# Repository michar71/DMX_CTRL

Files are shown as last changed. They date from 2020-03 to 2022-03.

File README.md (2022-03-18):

# DMX_CTRL
A DMX512-combatible light control platfrom for medium-complex projects.

There are currently standard solutions for light control that fill specific needs:
- DMX512 compatible stage lighting ($13 - $ 300) usually with Full RGB control and maybe XYZ Control
- Custom solutions for complex installations using WS1812 Strips (Fadecandy and others). This for Example: http://www.deniznicoleart.com/
- Progammable light controllers that can play back preprogrammed patterns that can get triggered by DMX512 (Chinese closed source products)

What is missing is a controller that combines the simple, low cost wiring and control of DMX512 with the flexibility of a customizable firmware and control options.

## Usage Case
The follwing is an outline of the current usage case for an art car and why a specific controller is needed. The art car has multiple light-elements that need central coordination/sequencing but also reacts to other stimulus:
- "Hoover Field" -> WS2812 Light Strips around the base that display a moving pattern syncronized with the speed of the car.
- "Engines" -> Simple RGB Strips that are playing a preprpogrammed startup/shutdown seuqence and a animation while moving
- "Internal Lights" -> Lantern with red LED's that are supposed to flicker and occasionally fail
- "Mood Lighting" -> White LED Strips that can be controlled in brightness
- "Centralized Control Panel" -> Touchscreen control to trigger and sequence effects (Either Cheap Windows Tablet or Raspberry Pi)

These are all usage cases that are not "Simple" DMX RGB-Light cases but also do not warrant complex solutions like FadeCandy that need a lot of programming, USB wiring and complex control computers.
While these effects could be achived with a handful of Arduinos it makes central control more compleicated as there is no common control bus easily available and the processing power of Arduinos is limited. 

## Feature List
-	Can act as DMX Master or Slave
-	Up to 2 WS8212 LED strips with up to 512 Pixel 
-	2x RGB LED/Strip and 1xRGBW LED/Strip support with up to 3A/12V per LED (Or optionally drive PWM controlled servos)
-	Configurable via USB/Serial Terminal
-	Up to 2 Analog Inputs (Can be used to control effects or act as Triggers)
-	8 Address Lines (Optional LCD via i2C and Encoder via GPIOs instead)
-	2 Mode Jumpers to hard-select options (Simple Mode (PWM Only) / Extended Mode (PWM+Strips+FX) and USB Enable/Disable)
-	Button to restore settings on startup or Test Mode
-	External UART or option to connect ESP8266 WiFi Board
-	USB to use as a Computer -> Master Bridge
-	Total Cost per Board ~$16 (Most of that (8$) are MOSFETs so it depends on how many LED channels are needed)
-	Board size 10x5 cm

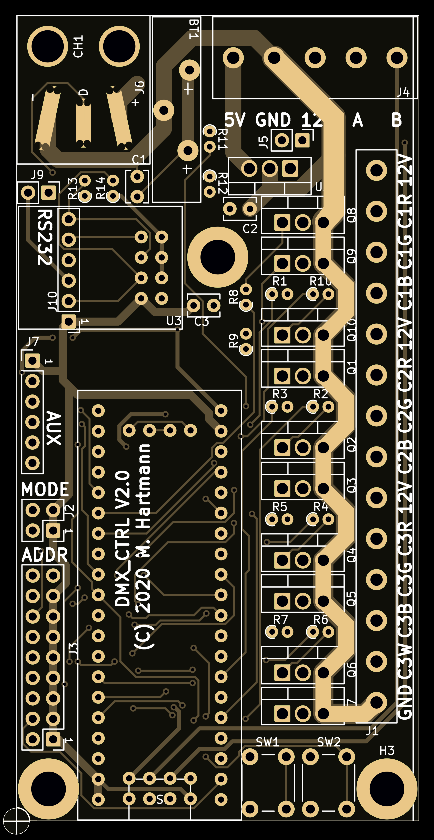
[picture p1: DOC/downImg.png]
Front PCB

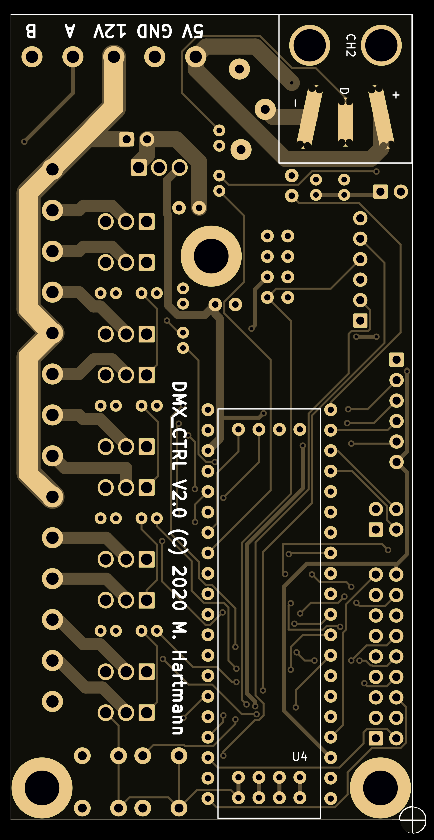
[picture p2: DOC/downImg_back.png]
Back PCB

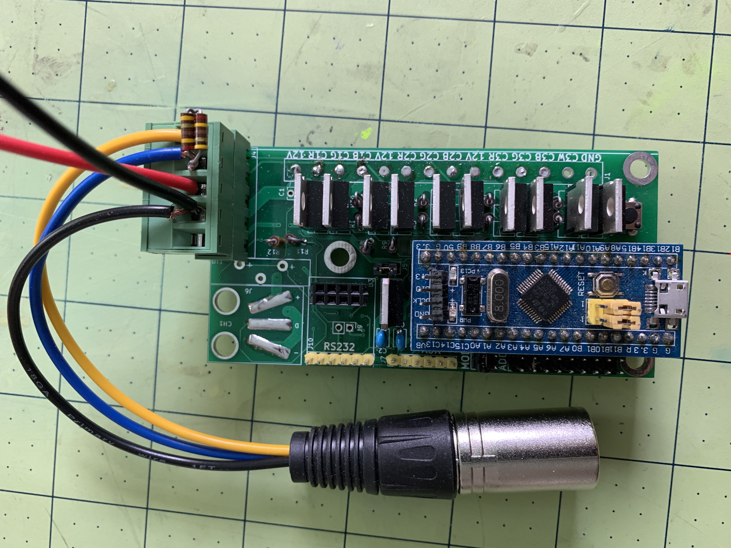
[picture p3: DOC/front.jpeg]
Front Assembled

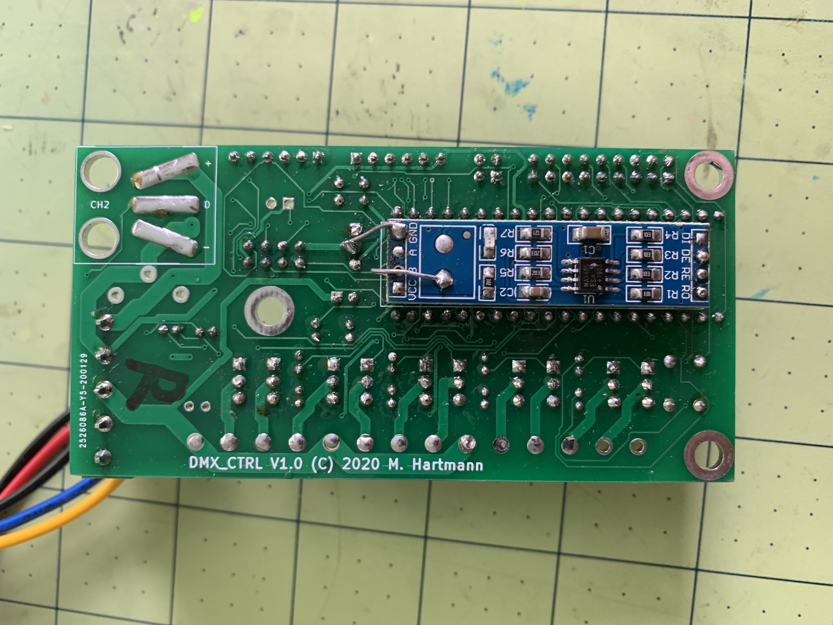
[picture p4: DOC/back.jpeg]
Back Assembled


## Current Status
- DMX512 Control of PWM Channels -> Working
- DMX Address setting via Jumpers -> Working
- Serial Shell to control/Save settings -> Working
- Load defaults on startup -> Working
- Clear settings (Hold button on power-up) -> Working
- Test Mode (Press button after power up, cycles through all LED channels) -> Working
- Triggers -> Working
- Plugin Manager -> Working
- Example Plugins -> Working
- WS2812 Support -> Working
- Serial Control (Wifi/Serial/USB) -> Working
- Serial DMX Protocol -> Working

## BOM Cost
The BOM cost for the simplest implementation is 
- $2.00 for the board
- $2.00 for the Bluepill STM32F103 Board
- $0.70 for the RS485 Module
- $4.00 for Misc (Resistors, pin headers, switch)
- $0.80 per Mosfet for controllable Channels
So somewhere between $9 to $17.

## Development Enironment
The software is developed with ST Microelectronics STM32CubeIDE 1.3.0
The software framework was generated with STM's ST CubeMX Solution (Config file included in DOC folder) and uses ST's HAL framework.
(Not my favorite but that's what they want you to use...)
I use a ST-Link V2.0 Clone to upload/Debug software. (Eventually there might be a USB DFU Firmware Upload Client....)

You can also use MS Visual Studio Code + PlatformIO. This is prefered if you run into issues with fake STM32's as PlatformIO uses openOCD which can set the device ID directly and program these devices.
There are currently a lot of bluepill STM32F103 board clones with fake STM32F103 circulating on Amazon. (I ended up with about 20...Aarrggghhh...)
As a workaround, you can edit the file ~/.platformio/packages/tool-openocd/scripts/target/stm32f1x.cfg and change the line:
set _CPUTAPID 0x1ba01477
to:
set _CPUTAPID 0x2ba01477

USB does not seem to work on my clones but I need to further test that....(I had issues like that before and usually it had to do with crappy USB cables...)

Here is another description how to fix it in STM32CubeIDE for openOCD debugging:
https://community.st.com/s/question/0D50X0000BTd7Zi/how-to-deal-wirh-could-not-verify-st-device-

Update: Not all fake chips have 128 kB, some only have 64 kB. At that point the FW can not write the configruation to page 127... This will cause a Hardware Fault. Change the EEPROM page in eeprom.h from 127 to 63 and modifiy the .id file to reflect the smaller FLASH size. (Less effects will obviously fit in there....)
I should probably figure out a way to detect flashsize automatically.....

## Serial Shell
[List of Serial Shell Commands](SHELL_COMMANDS.md)

## FX Plugin API
[FX Plugin Manual](FX_API.md)

## Notes

### DMX Registers
Depending on mode selection the module will present itself with either 11 or 26 DMX Registers.
In Mode 1 only the first 11 registers are available and provide simple PwM control.

In Mode 2 additional 15 registers are present for FX control. (WS2812B supporty will only be present in that mode...)
Except for the FX_SELECT register these don't do anything by default but have to be used in plugins. and functionality will vary.  

### Jumper Options

#### ADDRESS
The 8 Address Jumpers set the DMX Start address for the Registers.
As there are 512 possible DMX Addresses the Address set via jumpers will be multiplied by 2.

#### MODE
Jumper 1
Disabled = DMX Register Mode 1 (Only PWM Control, not FX)
Enabled  = DMX Register Mode 2 (PWM + WS2812B Strips, FX enabled

In DMX Mode 1 only the following Registers will be available:
#define MAX_BRIGHTNESS		0
#define CH1_RED				1
#define CH1_GREEN			2
#define CH1_BLUE			3
#define CH2_RED				4
#define CH2_GREEN			5
#define CH2_BLUE			6
#define CH3_RED				7
#define CH3_GREEN			8
#define CH3_BLUE			9
#define CH3_WHITE			10

In DMX Mode 2 additionally the following Registers will be available:
#define FX_SELECT		    	11
#define	STRIP1_PATTERN		12
#define STRIP1_SPEED		  13
#define STRIP1_SIZE			  14
#define STRIP1_COMPLEXITY	15
#define STRIP1_V1			    16
#define STRIP1_V2			    17
#define STRIP1_V3			    18
#define	STRIP2_PATTERN		19
#define STRIP2_SPEED		  20
#define STRIP2_SIZE			  21
#define STRIP2_COMPLEXITY	22
#define STRIP2_V1			    23
#define STRIP2_V2			    24
#define STRIP2_V3			    25

Jumper 2
Disabled = No USB Support (Saves a lot of memory)
Enabled  = Enables Serial Port via USB

### DMX Control Wires (A/B)
With my controller the follwing pinout works (Looking at a male connector):
Pin 1 = GND
Pin 2 = A
Pin 3 = B
Some controllers allow to swap A/B with a switch so your milage might vary....

### DMX Termination
DMX needs to be terminated at the end of the chain with a 160 Ohm Resistor.

### Power Supply
Board has been tested with 9 PWM channels with 216 RGB LED's with a total power consumption of 3.8A @ 12V.
If only 12V is supplied make sure to add J5 so the microcontroller is powered.

### Restoring Defaults
Pressing the button while powering up will erease all settings and restore the defaults.

### Test Mode
Pressing the button after powering up will turn on test mode where the module cycles through all lights to test wiring

### Triggers
The two trigger inputs  can be set up in different ways:

#### Direct Control
The analog value (0...3.3V) is directly mapped onto one of the control registers.
(For example an external inpout can be linked to the brightness of a channel or set the input parameter for an effect)

#### Threshold
A Specific value can be written to a specific control register wen crossing a threshold from low to high or from high to low. (For example a specific effect can be turned on/off via a switch)

### USB Port
USB Support can be complelty commented out in main.h as it saves a lot of RAM/Flash.
If USB Support is compiled in Mode Jumper 1 controls if it is eanbled or not.
USB has been confirmed working both witrh original STM32103F and STM clones but it is imperative to use good USB cables.
Also be aware that some boards will need R10 on the bluepill boards swapped from 10kOhm to 1.5kOhm. 
Both the Shell or the Serial DMX protocol can be run via USB.
On Win10 no special driver is needed, the device will be recognizied as a Serial port. The serial port emulation via USB is not speed-controlled so in theory data can be written at full 12Mbit/sec Full USB speed....

### Wifi/USB/Serial DMX Control
[TBD, Protocol Implemented, need sample App..]
[TBD, need ESP2866 Sample Code and Sample App]

### Master Control
TBD

### WS2812B
The LED strips seem to be very sensitive regarding the voltage on the data line. R11/R12 in theory protect the first LED from dying on transient overcurrent on startup but some LED strips won't work. In that case just bridge R11/R12....

### What's that strange connector footprint for the WS2812 connection?
The idea is to solder on wires and then use a zip-tie through the holes and hot-glue to secure the wires.
Past projects had big problems with wires breaking off or shortening out... Maybe this will work.....

## Acknowledgements
Example Code to use WS2812B on STM32 with DMA
https://michaeltien8901.github.io/stm32/2018/07/19/Using-STM32-SPI-For-LED-STRIP.html

DMX512 Example
https://github.com/carl3721/stm32-dmx512

## References
- DMX Pinout
https://interactive-online.com/resources/faq/dmx-512-connector-pinouts

- Fadecandy Webpage
https://github.com/scanlime/fadecandy

- Ultra-Cheap DMX Lights
(Just search for DMX512 RGB LED on ebay...)

## Part References
Bluepill Boards
https://stm32-base.org/boards/STM32F103C8T6-Blue-Pill.html

RS422 Converter
https://alexnld.com/product/2pcs-5v-max485-ttl-to-rs485-converter-module-board-for-arduino/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

(These can obviouslty be sourced way cheaper on ebay/alibaba/banggood... These links are just for reference...)

## Board Design
- Board designed with KiKad
- For various (Legacy) reasons it will need the KiCad 4.0 Symbol/Footprint Library installed...
- Board size is 100mm x 50mm. In theory these could be paneled for JCLPCB.com but there is no cost advantage if you include V-Grooves. You could just produce PCB's with two boards next to each other and cut them yourself but I haven't tried that....

## Known Issues (REV 1.0)
### Schematic:
- RX/TX Swapped on Serial Connector (TBD if they are right or wrong on ESP-01 connector...)
- GND not connected on RS485 Module
- Add Button for ESP8266 Button to trigger events on startup

### Layout:
- Make RS485 module base 2.54 mm longer (Or not.. apprently they come in two sizes.. Maybe add both sizes by adding another line of holes)
- Add silkscreen for Pin 1 to connectors
- Move RS232 Connector so it can be used in parallel with ESP-01 for Debug (Move further in so angled connector can be used....)
- Bluepill collides with mounting hole in corner
- Remove solder mask from high-current paths for tinning
- Battery collides with power connector
- Move labels for power supply to other side of connector or back
- Make holes for TO220 Larger so they fit flush
- RS485 module is rotated 180 Deg
- Create more room for programming connector on bluepill board by moving 5V Regulator
- Move Compyright Notice on Bottom to allow for Tinning
- For WS2812B Cable Connector, less extrame angle, 0.6mm smaller holes, Shink total size

## Known Issues (REV 2.0)
### Schematic:

### Layout:
- Bluepill collides with mounting hole in corner
- Panelize Board
- Mounting holes for RS485 Transceiver should have been 2.54mm smaller, not bigger?
- Holes for TO220 should have been even bigger
- No coating on 5V rail to WS2812B

## TODO
- Master Mode
- ESP-01 (ESP8266) Code/Example
- Serial DMX Protocol Example (In Processing....)
- RTC Support
- High Speed WS2812B USB Demo
- Overclocked Version

## Ideas
### WS2812B USB Mode
Run data as fast as possible via USB to 2 WS2812B strips.
(512 LED * 30 us) + 60 us = 15.4 ms (64 FPS)
512 Leds = (512 * 3) * 1.2 bytes = 1843 Bytes

1843 Bytesa * 64 Frames = 117964 Bytes
117964 Bytes * 2 = 235929 Bytes = 1887436 Bits
12 MBits = 12000000 Bits
12000000 Bits / 1887436 = 6.35
So in theory we have 6.35x the bandwidth we need to update 2x 512 LED's 64 Times/sec....

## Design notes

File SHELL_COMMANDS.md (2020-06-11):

# Shell Commands
Shell commands are available via the UART and via USB as default. They can be used to set up the system and test lights and inputs. After setting the parameters they can be stored to flash and will be reloaded at startup. (If you don't use the savesettings command all settings will be lost...)
Serial shell is enabled at 115 kBaud on the serial port. (Note that Rx and Tx are swapped at the moment....).
(If you need to program multiple devices it might jusat be easier to modify the defaults in settings.c...)
The UARTT and USB port share one shell instance so typing on both at the same time might yield unpredictable results. (But why would you do that????)
Defaults can be restored by pressing the button at startup. (This is also nessassary if the soruce code is modified to include new settings parameters as the structure in memeory will change and most likely lead to a crash on the next start when the defaults are loaded from flash-memeory...)

## Shell Commands

### help
Lists all the commands currently installed in the system.

### test [msg]
Loopback test to test shell. the string in msg will be printed to the shell

### getaddr
Retuns the current DMX Address configured by the ADDR jumpers

### getmode
Retuns the current mode configured by the MODE jumpers

### dumpadc
Print ADC values for channel A0/A1

### dumpregs
Print out all DMX Registers

### dumpsettings
Print out all Settings

### savesettings
Save Settings to Flash

### setpwm [id (0..2)] [ch (0..3)] [duty (0..65535)]
Set an individual PWM output to a specific value. 
(Direct HW access, can also be controlled by setting DMX Register)

### setbrightness [0..255]
Set the global brightness
(Direct HW access, can also be controlled by setting DMX Register)

### setoffset [ch (0..2)] [offset (-32766...32766)]
Sets an offset for either the Red, Green or Blue channels for the PWM outputs.
Value is an absolute offset for the PWM input.
(Used to calibrate the black level for a color channel)

### setgain [ch (0..2)] [gain (-32766...32766)]
Sets a gain multiplier for either the Red, Green or Blue channels for the PWM outputs.
Value is input / 100 so 100 = 1.0
(Used to calibrate the maximum output for a color channel)

### setgamma [ch (0..3)] [gamma (-32766...32766)]
Sets the gamma either for R,G,B or the strip. 
The gamma tables are stored in FLASH and recreated every time the command is executed.
Gamma is the value/100 so 220 = Gamma of 2.2 (Which is also the default value.)
For the strips gamma is not automatically applied and needs to be handled in the plugin code!

### setreg [reg] [val]
Set a DMX Register to a specific value

### storedefaultregs
Store the current settings of the DMX registers as defaults. These will be loaded and used even if no DMX input signal is present.
This does not store the values to FLASH but copies them to the settings. They will only be permanent AFTER issuing a 'savesettings' command.

### settriggerconfig  [trigger 0|1] [mode(0=None, 1=mapping, 2=switch)] [register (0..25] [level (0..255)]
Configure a trigger to a specific mode and define the DMX register that will be controlled by that trigger.
If the switch-mode is used 'level' defines the threshold level where we switch between the two control settingss

### settriggerctrl  [trigger 0|1] [Reg HiLo (0..25)] [Val HiLo (0..255)] [Reg LoHi (0..25)] [Val LoHi (0..255)]
Sets the control settings for 'switch' trigger mode.
It defines which DMX register will be set to which value when crossing the level set in the 'settriggerconfig' command both when crossing from low to high value and in the other direction.

### setfxmultiplier  [val (1,2,4)]
Sets the fx register multiplier. Currently the number of effects is limiited to 64 so this setup makes it possible to apply a multiplier to the fx register.
With a setting of 1 register value 0 corresponds to fx 0, value 1 to fx 1 and so on.
With a setting of 2 register value 0,1 corresponds to fx 0, value 2,3 to fx 1 and so on.
With a setting of 4 register value 0,1,2,3 corresponds to fx 0, value 4,5,6,7 to fx 1 and so on.
This is useful when using a manual controller with sliders to set the FX as it makes it easier to select one specific effect as it is available on up to 4 codes. (The sliders sometimes don't allow to set all possible values...)

### setstriplength [ch (0..2)] [length (0..1024)]
Sets the length of the WS2812B strips in number of pixels.
A restart is required after changing this setting and storing all settings as the memory is only allocated once during startup.

### setuartmode [0 = Serial, 1 = USB] [0 = Shell, 1 = Serial DMX]
Set the UART mode for the selected UART. storing the settings and a restart are required for these settings to become effective.
On the Serial UART we will still dump out debug messages but only respond to incoming serial DMX messages when selecting Serial DMX.

### switchuartmode [0 = Serial, 1 = USB]
Hard-switch the selected UART to Serial DMX Mode.

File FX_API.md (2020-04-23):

# FX Plugin Development
DMX CTRL support custom Effects plugin development both for the PWM controls and the WS2812B strip control. (It's actually the only way to add more/new effects..)
The following document outlines the general process of developing a plugin. 
As plugins are just source code they can pretty much do whatever they want but following these guidelines probably means they will also work.
As plugins are only source code they share the same memeory as the genral code so care needs to be taken to reduce memeory usage and evaluate if code might overflow the stack.
As all Plugin Code is instantiated at startup it should rely as little as possible on statically allocated RAM. 
To simplify development an API is provided to access system ressources. It is not nessassary to use this API but it simplifies things....
No comprehensive framework for LED Graphic effects is provided as it really depends on what a plugin will do. It's easier to copy from other code bases and reuse in an FX then try to make those libraries work with this codebase specifically as this codebase is pure C and a lot of arduino routines/libraries are C++.
Plugins that control the PWM Light override the settings programmed via DMX. (They should actually use the FX_API functions to set the DMX Registers directly as those values are copied to the lights after the plugin RUN call has been completed.)

## Plugin Framework
Plugins relay on two function calls:
- A Register Function call to register the plugin
- A Run Function call that is called periodically

No guarantee is given that the Run Function will be called at specic or even time intervals. (It depends on incoming DMX data, interrupts, the length of the WS2812B strips and other factors.) but the code is arranged in a way to keep calsl as regular as possible. For most effects that will be sufficient.
If a more accurate time base is needed (For example to calculate speed and velocity of LED lights in a LED strip) a function is Provided in the FX_API to get the time in milliseconds and calulate time intervals based on that.

## Plugin Installation
### Registering Plugins
Plugins need to be registered so the firmware can keep track of them. Registration is static you cannot add plugins during runtime.
To register a plugin it's header file needs to be included in 'fx_install.h" and it's registration routine added to the 'fx_install' function call.

### Plugin ID
The Plugin ID is the number that is used to activate it in the DMX FX_SELECT register. When plugins are registered they can either be registered with an absolute ID or ID = 0 which will add them to the next available spot.
If a plugin is registered with the same ID as an existing plugin it will overwrite that plugin.
Plugin ID 0 is special as it holds a "NULL" plugin that will not do anything.
(If plugins want to turn of the lights at the end of execution they either need to set all content to off/0 on termination or call another plugin that disables the lights)

### Plugin init structure
In the plugin intialisation routine the plugin needs to pass over an init structure to the underlying plugin list manager.

The structure is declasred as this:
'''
//Effect Parameters
typedef struct{
	t_fx_type type;
	t_fx_mode mode;
	uint8_t	  next_fx;	//Next effect if duration != 0. If set to 0 turns off effects
	char      fxname[9];
	uint32_t  duration;   //Duration in Frames. If 0 runs continuously otherwise advances to next effect after x frames
	fx_run_t fx_run_pointer;
}s_fx_param;
'''

The structure should be declared as const so no RAM is used.
'''
static const s_fx_param param = {PWM_FX,MODE_CONTINOUS,0,"PPULSE",0,fx_pwm_pulsing_light_run};

void fx_pwm_pulsing_light(uint8_t fx_num)
{
	//Register effect
	register_fx(&param,fx_num);
}
'''

### Plugin Type
Plugins can be one of 3 different type:
- PWM Control Omly
- Strip Control Only
- Both

'''
//Types of Effects
typedef enum{
	PWM_FX,			//An effect that controls the PWM outputs
	STRIP_FX,		//An Effect that controls the LED Strips
	PWM_STRIP_FX	//An Effect that controls both
}t_fx_type;
'''

### Plugin Mode
Plugins can be one of three different modes:
- Continous -> The Plugin will run forever unless the user selects a different effect
- Single Shot -> The plugin will run once for the frames defined in 'duration' and then extecute the 'next_fx' plugin or fall back to the last one
- Loop Mode -> The plugin will run for the frames defined in 'duration' but then start again after running through the INIT sequence. (Careful with allocating memeory in the INIT sequence so memeory does't get allcoated every time...)

'''
//Type of Modes
typedef enum{
	MODE_CONTINOUS,  	//Effect runs until some other effect is selected
	MODE_SINGLE_SHOT,	//Effect Runs once for duration and returns to the last effect
	MODE_LOOP 			//Effect Runs for duration and then INIT State is called again once
}t_fx_mode;
'''

### Plugin next_fx
The 'next_fx' Plugin parameter determines what plugin will be activated either after the 'duration' parameter expires or the plugin self-terminates.

### Plugin fxname
The anme field can store up to 8 characters for the name of the plugin. (Mostly used for debugging)

### Plugin Duration
The 'duration' field holds the duration the plugin is supposed to run in number of frames. At the end of the duration the plugin will terminate and either fall back to the last plugin or the plugin defined in 'next_fx'.

### Plugin Run Function
The Run function will be called one at the start of the plugin, for every succesive frame and once at the end.

The function call looks like this:
'''
t_fx_result fx_run(t_fx_state state,uint32_t framecount,const uint32_t duration)
'''
And the function is part of the plugin defnition structure.

The state is one of the following states:

'''
//State for the current function call. It is guaranteed that
//FX_INIT will be executed once on start and FX_END once effect ends.
typedef enum{
	FX_INIT,
	FX_RUN,
	FX_END,
	FX_DONE
}t_fx_state;
'''

### Plugin Error Codes
The plugin run routine needs to return one of the following erro codes:
'''
//Type of Return Values
typedef enum{
	FX_OK,
	FX_COMPLETED,
	FX_RUNNING,
	FX_ERROR
}t_fx_result;
'''
If a plugin wants to self-terminate it has to return a FX_COMPLETED errorcode.

### Self-Terminating Plugins
Plugins can end operation either because the user selects a different plugin, the duration has expired in single-shot mode or the plugin self-termines by returning the FX_COMPLETED errorcode.
After that code is returned the plugin will be called once more with the FX_END state.

## Plugin API
To simplify development all nessassary header files and helper routines are accesible via the fx_api.h header file.

### Access to DMX Registers
DMX Register values should be accessed through the 'get_DMX_variable' function.
Register definitions are provided in the fx_api.h file.
To optimize code register mappings as arrays have been provided to more efficiently access registers, for example:
'''
    //Loop through both channels
    for (uint8_t ii = 0;ii<CH_MAX;ii++)
    {
        step[ii] = get_DMX_variable(DMX_CH_REG[ii][DMX_STRIP_SIZE]);
    }
'''
If the PWM DMX registers are modified while the plugin is running those values might overwrite any changes made by the Plugin! If that is an issue it might be better to set the value of the DMX PWM registers directly through the '' function call.

### Access to PWM Controls
PWM Channels can either be accessed as individual channels or RGB channels with the following functions:
'''
void set_pwm_light(uint8_t index, uint8_t val);
void set_pwm_timer_channel(uint8_t ch, uint8_t r, uint8_t g, uint8_t b);
'''
Additionally PWM parameters can also be changed 

### Access to WS2812B Strips
Access to the WS2812B strips is provided through the following functions:
'''
void WS2812B_setPixelColor(t_stripchannel ch,uint16_t n, uint8_t r, uint8_t g, uint8_t b);
void WS2812B_setPixelColorDirect(t_stripchannel ch,uint16_t n, uint32_t c);
void WS2812B_setBrightness(t_stripchannel ch,uint8_t brightness);
void WS2812B_clear(t_stripchannel ch);
uint8_t WS2812B_getBrightness(t_stripchannel ch);
uint16_t WS2812B_numPixels(t_stripchannel ch);
uint32_t WS2812B_Color(uint8_t r, uint8_t g, uint8_t b);
'''
These are equivalent to the Adafruit Led Library function calls.

### Overall Brightness
Overall Brightness can be set independently for PWM and Strips through:
'''
//Set Overall Brightness
void set_pwm_brightness(uint8_t val);
void set_strip_brightness(uint8_t val);
'''
(If both PWM and Strips need to be linked to the MAX_BRIGHTNESS register it needs to be set in the plugin.)

### Access to System Hardware
- Plugins can access the Analog Trigger Values from A0/A1 inputs through the 'get_tigger_val' FX_API function call. 
- Plugins can access the System Timer through the 'millisec' FX_API function call. 

## Plugin Example
'''
//Include what's nessassary here
#include "fx_api/fx_api.h"
#include "fx/fx_test.h"

static const s_fx_param param = {PWM_FX,MODE_CONTINOUS,0,"PRUN",0,fx_run};

//This gets called form fx_install.h
void fx_install(uint8_t fx_num)
{
	//Register effect
	register_fx(&param1, fx_num);
}

//This is the main run routine for the plugin. Everything happenes here...
t_fx_result fx_run(t_fx_state state,uint32_t framecount,const uint32_t duration)
{
	switch(state)
	{
		case FX_INIT:
			//Plugin insitalisation like zeroing out variables, allocating memeory or setting up HW shoudl happen here
			return FX_OK;
		case FX_RUN:
			//Execiting stuff like controlling the lights should happen here.
			return FX_RUNNING;
		case FX_END:
			//Deallocate memeory and clean up here...
			return FX_COMPLETED;
		case FX_DONE:
            //This should never happen...
			break;
	}
	return FX_ERROR;
}
'''

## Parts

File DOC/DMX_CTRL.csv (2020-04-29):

Id | Designator | Package | Quantity | Designation | Supplier and ref
1 | U1 | ChinaBluePill | 1 | ChinaBluePill
2 | U2 | TO-220-3_Vertical | 1 | uA7805
3 | Q7,Q6,Q5,Q4,Q3,Q2,Q10,Q1,Q9,Q8 | TO-220-3_Vertical | 10 | IXTP3N50D2
4 | U4 | RS485_Transeiver | 1 | RS485_Transeiver
5 | J6 | WS2812_Dual_SMD | 1 | WS2812_Conn
6 | SW2,SW1 | SW_PUSH_6mm_H8mm | 2 | SW_Push
7 | R14,R13,R1,R2,R3,R4,R5,R6,R7,R8,R9,R10 | R_Axial_DIN0204_L3.6mm_D1.6mm_P1.90mm_Vertical | 12 | 1K
8 | H3,H1,H2 | MountingHole_4.3mm_M4_DIN965_Pad | 3 | MountingHole
9 | U3 | ESP-01 | 1 | ESP-01
10 | R11,R12 | R_Axial_DIN0204_L3.6mm_D1.6mm_P1.90mm_Vertical | 2 | 330
11 | BT1 | Vertical_3032_Coin_Batter_Holder | 1 | Battery_Cell
12 | C1 | C_Disc_D3.8mm_W2.6mm_P2.50mm | 1 | 100nF
13 | C2 | C_Disc_D3.8mm_W2.6mm_P2.50mm | 1 | 0.22uF
14 | C3 | C_Disc_D3.8mm_W2.6mm_P2.50mm | 1 | 0.1uF
15 | J2 | PinHeader_2x02_P2.54mm_Vertical | 1 | MODE
16 | J3 | PinHeader_2x09_P2.54mm_Vertical | 1 | ADDR
17 | J5 | PinHeader_1x02_P2.54mm_Vertical | 1 | 12V Link
18 | J7 | PinHeader_1x06_P2.54mm_Vertical | 1 | AUX
19 | J9 | PinHeader_1x02_P2.54mm_Vertical | 1 | 3V3 UART
20 | J10 | PinHeader_1x06_P2.54mm_Vertical | 1 | TTL_UART
21 | J1 | LED_CONN_x14_5.08 | 1 | LED_CONN
22 | J4 | PWR_CONN_x5_5.08 | 1 | PWR

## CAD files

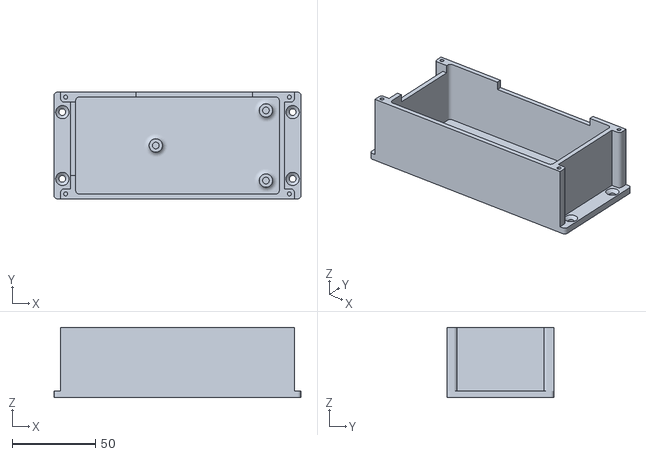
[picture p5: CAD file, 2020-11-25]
HOUSING/CTRL_BOX.stl
148.0 x 64.0 x 42.0

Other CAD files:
HOUSING/DMX_CTRL_BOX.FCStd
HOUSING/DMX_CTRL_BOX_LID.FCStd

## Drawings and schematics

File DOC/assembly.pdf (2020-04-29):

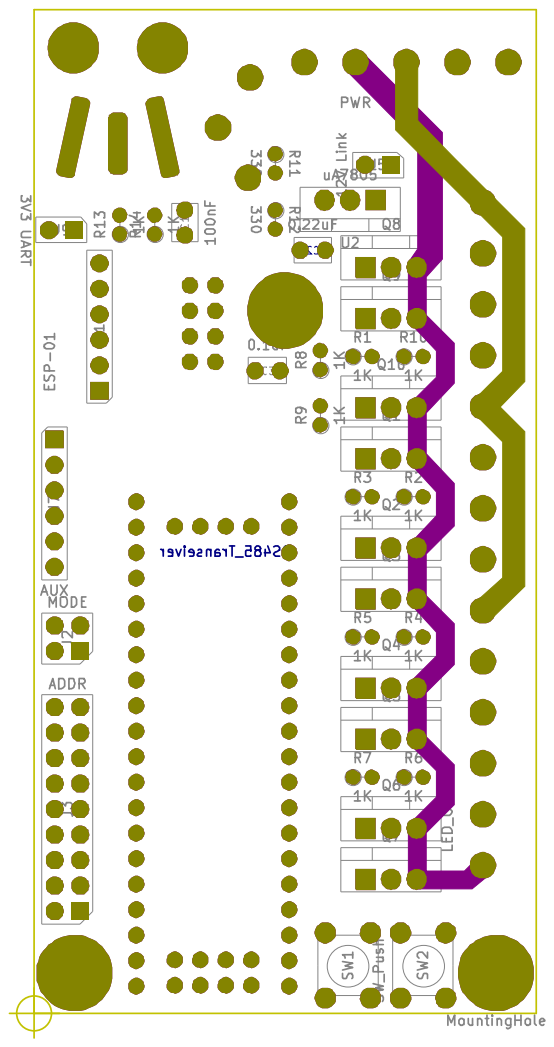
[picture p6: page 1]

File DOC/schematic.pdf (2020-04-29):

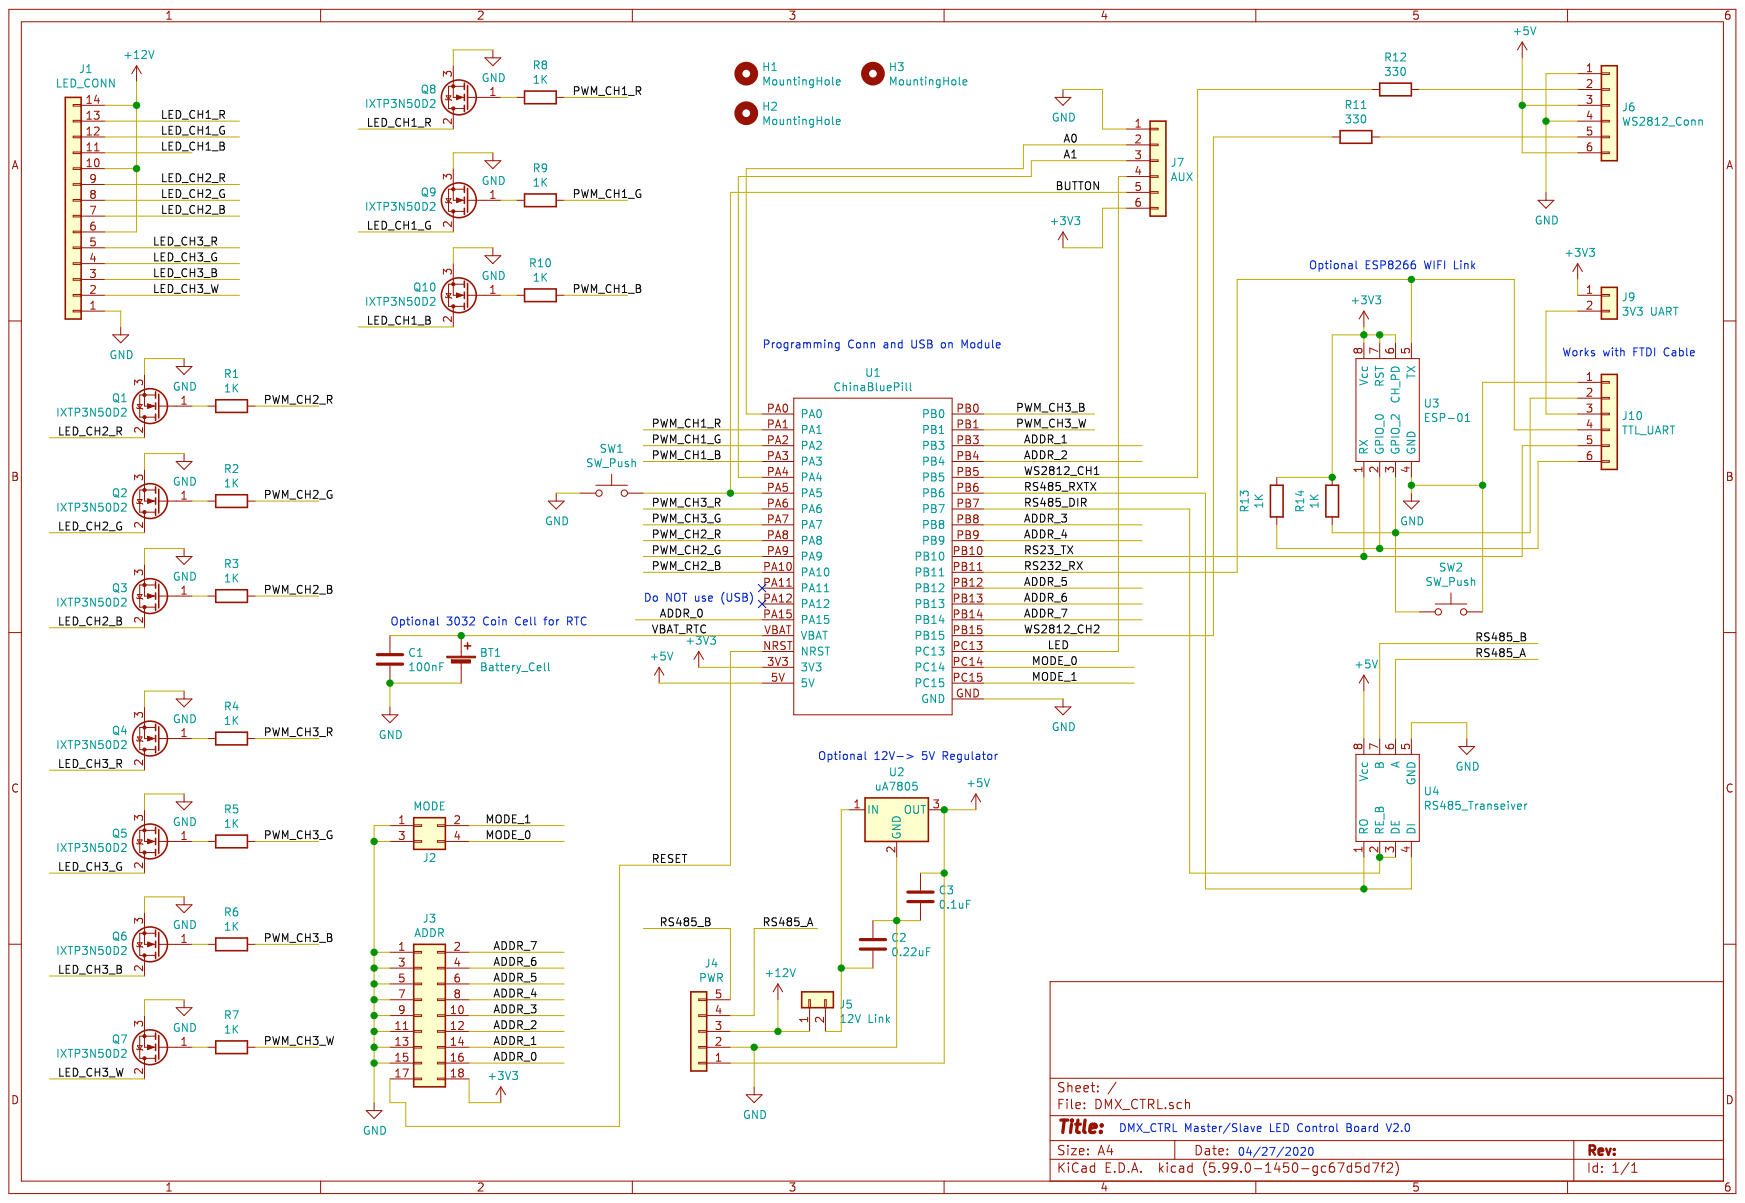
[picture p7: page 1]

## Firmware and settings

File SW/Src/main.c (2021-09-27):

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

/* Includes ------------------------------------------------------------------*/
#include "main.h"
#ifdef SUPPORT_USB
#include "usb_device.h"
#endif
#include "dmx512_rec.h"
#include "dmx512_config.h"
#include "serial_tracer.h"
#include "shell.h"
#include "gpio_control.h"
#include "pwm_control.h"
#include "light_update.h"
#include "settings.h"
#include "triggers.h"
#include "testmode.h"
#include "fx_manager.h"
#include "fx_list.h"
#include "WS2812B/WS2812B.h"
#include "serial_dmx_parser.h"
#include "ring_buffer.h"
#include "gammactrl.h"

/* USER CODE BEGIN Includes */
#include <stdint.h>

/* USER CODE END Includes */

ADC_HandleTypeDef hadc1;
ADC_HandleTypeDef hadc2;

IWDG_HandleTypeDef hiwdg;

UART_HandleTypeDef huart1;
UART_HandleTypeDef huart3;

SPI_HandleTypeDef hspi1;
SPI_HandleTypeDef hspi2;
DMA_HandleTypeDef hdma_spi1_tx;
DMA_HandleTypeDef hdma_spi2_tx;

/* USER CODE BEGIN PV */
uint8_t testmode = 0;

uint8_t UART_mode_SERIAL = 0;
uint8_t UART_mode_USB = 0;
uint8_t USB_Active = 0;

uint32_t frame_ms;

//UART Ringbuffer
#define RX_BUFF_SIZE 128
rb_att_t rx_buff_dmx;
rb_att_t rx_buff_shell;

/* USER CODE END PV */

void SystemClock_Config(void);
static void MX_GPIO_Init(void);
static void MX_ADC1_Init(void);
static void MX_ADC2_Init(void);
static void MX_IWDG_Init(void);
static void MX_USART1_UART_Init(void);
static void MX_USART3_UART_Init(void);
static void MX_SPI1_Init(void);
static void MX_SPI2_Init(void);
static void MX_DMA_Init(void);

/**
  * @brief  The application entry point.
  * @retval int
  */
int main(void)
{
  /* USER CODE BEGIN 1 */
  uint32_t last_frame_ms;
  uint32_t current_frame_ms;
  /* USER CODE END 1 */
  

  /* MCU Configuration--------------------------------------------------------*/

  /* Reset of all peripherals, Initializes the Flash interface and the Systick. */
  HAL_Init();

  /* Configure the system clock */
  SystemClock_Config();

  /* Initialize all configured peripherals */
  MX_GPIO_Init();
  //Turn LED for Test
  HAL_GPIO_WritePin(LED_GPIO_Port, LED_Pin, GPIO_PIN_RESET);
  MX_ADC1_Init();
  MX_ADC2_Init();
#ifdef ENABLE_WATCHDOG
  MX_IWDG_Init();
#endif
  MX_USART1_UART_Init();
  MX_USART3_UART_Init();
  MX_SPI1_Init();
  MX_SPI2_Init();
  MX_DMA_Init();


  /* USER CODE BEGIN 2 */
  //Wait some time otherwise some boards screw up at startup and don't read back the config pins correctly...
  for (uint32_t w = 0;w<5000;w++)
      print_no_newline(" ");

  //Dump Startup info
  print("");
  print("-------------");
  print("%s V%d.%d",PROG_NAME,VERSION_MAJOR,VERSION_MINOR);
  print("-------------");
  print("");

 if(__HAL_RCC_GET_FLAG(RCC_FLAG_IWDGRST) == SET)
 {
	 print("Restart due to IWDG Reset");
  	  __HAL_RCC_CLEAR_RESET_FLAGS();
 }


 //Set Mode/Address from Address Pins
 dmx512_init(get_mode_from_pins(),get_addr_from_pins()*2);  //Address x2 so we can spread out the 8 Jumpers over 512 Addresses
 print("DMX512 Config complete");


#ifdef SUPPORT_USB
 if ((get_mode_from_pins() & 0x02) != 0)
 {
	 USB_Active = 1;
	 MX_USB_DEVICE_Init();
	 print("USB Enabled");
 }
 else
 {
	 print("USB Disabled");
 }
#else
 print("USB Hard Disabled");
#endif

 if(ring_buffer_init(&rx_buff_shell, RX_BUFF_SIZE) != RB_OK)
	 print("Shell Ring Buffer Init FAILED");
 else
	 print("Shell Ring Buffer Init Complete");

 if(ring_buffer_init(&rx_buff_dmx, RX_BUFF_SIZE) != RB_OK)
	 print("Serial DMX Ring Buffer Init FAILED");
 else
	 print("Serial DMX Ring Buffer Init Complete");

 //Setup UART1 (RS485)/DMX512 Receiver
 dmx512_rec_init();
 print("DMX512 Init complete");

  //Init/Setup PWM for Lights
  init_timers();
  print("Timer Init complete");
      
  //Init Defaults
  init_settings();
  print("Default Settings Initialized");

  // If Button is not pressed Load Defaults
  print("Loading Settings...");
  if (0 == check_button())
  {
	  if (false == load_settings())
	  {
		  //Set Default Gamma Table
		  init_settings();
		  recalcGamma();
		  save_settings();
		  print("Defaults created");
	  }

	  UART_mode_SERIAL = settings.UART_Mode_UART;
	  UART_mode_USB = settings.UART_Mode_USB;
	  print("Setting loaded");
  }
  else
  {
	  //Set Default Gamma Table
	  recalcGamma();
	  save_settings();
	  print("Defaults restored");
  }

  //Set Defaults
  apply_settings();

  print("Settings complete");

  if (DMX_MODE2 == get_mode())
  {
	  print("FX Installation Start");
	  init_fx_list();
	  install_fx();
	  print("FX Installation Finished");

     if (WS2812B_init(CH1,settings.strip1_length))
     {
	   print("WS2812B CH1 Init complete");
	   WS2812B_clear(CH1);
	   WS2812B_show(CH1);
     }
	 else
	 {
	   print("WS2812B CH1 Init FAILED");
	 }

     if (WS2812B_init(CH2,settings.strip1_length))
     {
	   print("WS2812B CH2 Init complete");
	   WS2812B_clear(CH2);
	   WS2812B_show(CH2);
     }
	 else
	 {
	   print("WS2812B CH2 Init FAILED");
	 }
     print("DMX Mode 2 Active");
  }
  else
  {
	  print("DMX Mode 1 Active");
  }

  init_update_lights();
  print("PWM Update Init complete");

  init_trigger();
  print("Trigger Init complete");

  print("Shell Active");

  //Shell is ready....
  print_no_newline("DBG>");

  //Get first frame time
  last_frame_ms = HAL_GetTick();

  //Turn LED off at completion of init
  HAL_GPIO_WritePin(LED_GPIO_Port, LED_Pin, GPIO_PIN_SET);
  /* USER CODE END 2 */

  /* Infinite loop */
  /* USER CODE BEGIN WHILE */
  while (1)
  {
    /* USER CODE END WHILE */

    /* USER CODE BEGIN 3 */

	//Handle Test Shell and DMX Serial Process
	shell_process();
	dmx_serial_process();

	//Try to produce a constant framerate...
	current_frame_ms = HAL_GetTick();
	if (settings.frame_ms_target > 0)
	{
		//Loop until time for frame has elapsed...
		while ((current_frame_ms - last_frame_ms) < settings.frame_ms_target)
		{
			shell_process();
			dmx_serial_process();
			current_frame_ms = HAL_GetTick();
		}
	}

	//Calulate framerate
	frame_ms = current_frame_ms - last_frame_ms;
	last_frame_ms = current_frame_ms;

  //Check for Comm Timeout
  if ((COMM_TIMEOUT != 0) && (frame_ms > (last_packet_ms + COMM_TIMEOUT))) 
  {
    //Lets reset Registers to defaults....
    apply_settings();
  }

	if (testmode)
	{
		testmode = process_testmode();
		//Restore settings
		if (testmode == 0)
		{
			update_pwm_lights(1);
			if (DMX_MODE2 == get_mode())
			{
				WS2812B_clear(CH1);
				WS2812B_show(CH1);
				WS2812B_clear(CH2);
				WS2812B_show(CH2);
			}
		}
		else
		{
			if (DMX_MODE2 == get_mode())
			{
				WS2812B_test(CH1);
				WS2812B_show(CH1);
				WS2812B_test(CH2);
				WS2812B_show(CH2);
			}
		}
	}
	else
	{
		//Button pushed
		if (1 == check_button())
		{
			testmode = 1;
		}

		//	Read ADC and Handle Controls/Triggers
		process_trigger();
		//  Run Effect Programs if DMX Mode 2 is enabled
		if (DMX_MODE2 == get_mode())
		{
			run_fx();
			//Update WS2812 Data
			//TBD Should this be done from Here by
			//1) calling Show every Frame
			//Or
			//2) from inside the FX only when it is needed?
			//Going with option 1 for the moment. as the timing is more predictable...
			WS2812B_show(CH1);
			WS2812B_show(CH2);
		}

		//  Set PWM Lights
		update_pwm_lights(0);
		update_fx();
	}

	//  Reset Watchdog
#ifdef ENABLE_WATCHDOG
	HAL_IWDG_Refresh(&hiwdg);
#endif

  }
  /* USER CODE END 3 */
}

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


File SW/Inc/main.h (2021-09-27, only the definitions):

#define PROG_NAME "DMX_CTRL"
#define VERSION_MAJOR 1
#define VERSION_MINOR 1
#define COMM_TIMEOUT 5000
#define LED_Pin GPIO_PIN_13
#define LED_GPIO_Port GPIOC
#define MODE_0_Pin GPIO_PIN_14
#define MODE_0_GPIO_Port GPIOC
#define MODE_1_Pin GPIO_PIN_15
#define MODE_1_GPIO_Port GPIOC
#define ANALOG_0_Pin GPIO_PIN_0
#define ANALOG_0_GPIO_Port GPIOA
#define CH1_R_Pin GPIO_PIN_1
#define CH1_R_GPIO_Port GPIOA
#define CH1_G_Pin GPIO_PIN_2
#define CH1_G_GPIO_Port GPIOA
#define CH1_B_Pin GPIO_PIN_3
#define CH1_B_GPIO_Port GPIOA
#define ANALOG_1_Pin GPIO_PIN_4
#define ANALOG_1_GPIO_Port GPIOA
#define BUTTON_Pin GPIO_PIN_5
#define BUTTON_GPIO_Port GPIOA
#define CH2_R_Pin GPIO_PIN_6
#define CH2_R_GPIO_Port GPIOA
#define CH2_G_Pin GPIO_PIN_7
#define CH2_G_GPIO_Port GPIOA
#define CH2_B_Pin GPIO_PIN_0
#define CH2_B_GPIO_Port GPIOB
#define CH2_W_Pin GPIO_PIN_1
#define CH2_W_GPIO_Port GPIOB
#define RS232_TX_Pin GPIO_PIN_10
#define RS232_TX_GPIO_Port GPIOB
#define RS232_RX_Pin GPIO_PIN_11
#define RS232_RX_GPIO_Port GPIOB
#define ADDR_5_Pin GPIO_PIN_12
#define ADDR_5_GPIO_Port GPIOB
#define ADDR_6_Pin GPIO_PIN_13
#define ADDR_6_GPIO_Port GPIOB
#define ADDR_7_Pin GPIO_PIN_14
#define ADDR_7_GPIO_Port GPIOB
#define WS8212_CH2_Pin GPIO_PIN_15
#define WS8212_CH2_GPIO_Port GPIOB
#define CH3_R_Pin GPIO_PIN_8
#define CH3_R_GPIO_Port GPIOA
#define CH3_G_Pin GPIO_PIN_9
#define CH3_G_GPIO_Port GPIOA
#define CH3_B_Pin GPIO_PIN_10
#define CH3_B_GPIO_Port GPIOA
#define ADDR_0_Pin GPIO_PIN_15
#define ADDR_0_GPIO_Port GPIOA
#define ADDR_1_Pin GPIO_PIN_3
#define ADDR_1_GPIO_Port GPIOB
#define ADDR_2_Pin GPIO_PIN_4
#define ADDR_2_GPIO_Port GPIOB
#define WS8212_CH1_Pin GPIO_PIN_5
#define WS8212_CH1_GPIO_Port GPIOB
#define RS485_RXTX_Pin GPIO_PIN_6
#define RS485_RXTX_GPIO_Port GPIOB
#define RS485_DIR_Pin GPIO_PIN_7
#define RS485_DIR_GPIO_Port GPIOB
#define ADDR_3_Pin GPIO_PIN_8
#define ADDR_3_GPIO_Port GPIOB
#define ADDR_4_Pin GPIO_PIN_9
#define ADDR_4_GPIO_Port GPIOB

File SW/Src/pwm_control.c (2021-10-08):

/*
 * pwm_control.c
 *
 *  Created on: Feb 14, 2020
 *      Author: Michael Hartmann
 */

#include <stm32f1xx.h>
#include "pwm_control.h"
#include <stm32f1xx_hal_tim.h>
#include <string.h>
#include "shell.h"


TIM_HandleTypeDef timerinfo[3]; //(CH1 = 0 = htim2,CH2 = 1 = htim3,CH3 = 2 = htim1)

//Channels CH1,CH2,CH3 for RGBW...
const uint32_t channelinfo[3][4] = {{TIM_CHANNEL_2,TIM_CHANNEL_3,TIM_CHANNEL_4,255},
									{TIM_CHANNEL_1,TIM_CHANNEL_2,TIM_CHANNEL_3,255},
		                            {TIM_CHANNEL_1,TIM_CHANNEL_2,TIM_CHANNEL_3,TIM_CHANNEL_4}};
		
//1076

#define MAX_PWM 60000
const uint32_t pwm = MAX_PWM;  //1067
const uint32_t div = TIM_CLOCKDIVISION_DIV1;//TIM_CLOCKDIVISION_DIV1
const uint32_t pre = 2;//1
uint32_t maxPWM = MAX_PWM;

void init_timers(void)
{
	//Start Clocks to timer BLock
	__HAL_RCC_TIM1_CLK_ENABLE();
	__HAL_RCC_TIM2_CLK_ENABLE();
	__HAL_RCC_TIM3_CLK_ENABLE();

	//Init Timers as PWM
	PWM_Timer_Init(PWM_CH1,pre,pwm,div,0);
	PWM_Timer_Init(PWM_CH2,pre,pwm,div,0);
	PWM_Timer_Init(PWM_CH3,pre,pwm,div,0);
}

void PWM_Timer_Init(pwmtimerid_t ID,uint32_t prescaler,uint32_t pwm_max, uint32_t clockdiv, uint32_t reinit)
{

	  TIM_MasterConfigTypeDef sMasterConfig;
	  TIM_OC_InitTypeDef sConfigOC;
	  TIM_ClockConfigTypeDef sClockSourceConfig;

	  memset(&sConfigOC, 0, sizeof(sConfigOC));
	  memset(&sMasterConfig, 0, sizeof(sMasterConfig));
	  memset(&sClockSourceConfig, 0, sizeof(sClockSourceConfig));

	  maxPWM = pwm_max;

	  switch(ID)
	  {
	  	  case PWM_CH1:
	  		timerinfo[ID].Instance = TIM2;
		  break;
	  	  case PWM_CH2:
	  		timerinfo[ID].Instance = TIM1;
		  break;
	  	  case PWM_CH3:
	  		timerinfo[ID].Instance = TIM3;
		  break;
	  }

	  timerinfo[(uint8_t)ID].Init.Prescaler = prescaler;
	  timerinfo[(uint8_t)ID].Init.CounterMode = TIM_COUNTERMODE_UP;
	  timerinfo[(uint8_t)ID].Init.Period = maxPWM-1;
	  timerinfo[(uint8_t)ID].Init.ClockDivision = clockdiv;
	  timerinfo[(uint8_t)ID].Init.RepetitionCounter = 0;
	  if (HAL_TIM_Base_Init(&timerinfo[(uint8_t)ID]) != HAL_OK)/* to use the Timer to generate a simple time base for TIM1 */
	  {
		  print("Timer Init Error 1");
	  }

	  sClockSourceConfig.ClockSource = TIM_CLOCKSOURCE_INTERNAL;//the default clock is the internal clock from the APBx, using this function
	  if (HAL_TIM_ConfigClockSource(&timerinfo[(uint8_t)ID], &sClockSourceConfig) != HAL_OK)//Initializes the TIM PWM Time Base according to the specified
	 //parameters in the TIM_HandleTypeDef and create the associated handle.
	   {
		  print("Timer Init Error 2");
	   }


	  if (HAL_TIM_PWM_Init(&timerinfo[(uint8_t)ID]) != HAL_OK)
	  {
		  print("Timer Init Error 3");
	  }

	  if (reinit != 0)
		  return;

	  sConfigOC.OCMode = TIM_OCMODE_PWM1;
	  sConfigOC.OCIdleState = TIM_OCIDLESTATE_SET;
	  sConfigOC.Pulse = maxPWM/2; /* 50% duty cycle is 538, set to 0 initially*///
	  sConfigOC.OCPolarity = TIM_OCPOLARITY_HIGH;
	  sConfigOC.OCNPolarity = TIM_OCNPOLARITY_HIGH;
	  sConfigOC.OCFastMode = TIM_OCFAST_ENABLE;
	  sConfigOC.OCIdleState = TIM_OCIDLESTATE_RESET;
	  sConfigOC.OCNIdleState = TIM_OCNIDLESTATE_RESET;

	  for (int ii=0;ii<4;ii++)
	  {
		  if (channelinfo[(uint8_t) ID][ii] != 255)
		  {
			  if (HAL_OK != HAL_TIM_PWM_ConfigChannel(&timerinfo[(uint8_t)ID], &sConfigOC, channelinfo[(int8_t)ID][ii]))
			  {
				  print("Timer Init Error 4");
			  }

		  }
	  }

	 // HAL_TIM_MspPostInit(&timerinfo[(uint8_t)ID]);//output pin assignment
	  HAL_TIM_Base_Start(&timerinfo[(uint8_t)ID]); //Starts the TIM Base generation

	  for (int ii=0;ii<4;ii++)
	  {
		  if (channelinfo[(uint8_t) ID][ii] != 255)
		  {
			  if (HAL_OK != HAL_TIM_PWM_Start(&timerinfo[(uint8_t)ID], channelinfo[(int8_t)ID][ii]))
			  {
				  print("Timer Init Error 5");
			  }

		  }
	  }
}



//Setup PWM
void configPWM(pwmtimerid_t ID,pwmchid_t channel, uint16_t duty)
{
	  if (channelinfo[(uint8_t) ID][channel] != 255)
	  {
	  __HAL_TIM_SET_COMPARE(&timerinfo[ID],  channelinfo[(uint8_t)ID][(uint8_t)channel], duty);
	  }
}


void setPWMdirect(uint8_t id, uint8_t ch, uint16_t val)
{
	configPWM((pwmtimerid_t)id,(pwmchid_t)ch, (uint16_t)val);
}


uint32_t getMaxPWM(void)
{
	return maxPWM;
}

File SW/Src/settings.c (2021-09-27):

/*
 * settings.c
 *
 *  Created on: Feb 14, 2020
 *      Author: Michael Hartmann
 */
#include "settings.h"
#include "eeprom.h"
#include "dmx512_config.h"
#include <string.h>
#include <stdio.h>
#include <stdlib.h>
#include <stdio.h>
#include "shell.h"
#include "main.h"


#define PAGE_SETTING_START 123
#define PAGE_SETTING_COUNT 4



uint16_t makeVersion(void)
{
	return ((uint16_t)VERSION_MAJOR<<8) + (uint16_t)VERSION_MINOR;
}

void init_settings(void)
{
	//Set everything to 0....
	memset(&settings,0,sizeof(settings_s));

	settings.configID[0] = 'D';
	settings.configID[1] = 'M';
	settings.configID[2] = 'X';
	settings.configID[3] = 'C';
	settings.configFWversion = makeVersion();

	//Set deviations from 0...
	settings.max_brightness = 255;

	settings.frame_ms_target = 0;

	settings.strip1_length = 9;
	settings.strip2_length = 9;

	settings.offset_red = -100;
	settings.gain_red = 100;    //Gain * 100
	settings.gamma_red = 220;   //Gamma * 100
	settings.offset_green = -80;
	settings.gain_green =100;    //Gain * 100
	settings.gamma_green = 220;   //Gamma * 100
	settings.offset_blue = -80;
	settings.gain_blue = 100;    //Gain * 100
	settings.gamma_blue = 220;   //Gamma * 100

	settings.gamma_strip = 220; //Gamma * 100

	settings.fx_multiplier = 1;
	settings.UART_Mode_UART = (uint8_t)UART_MODE_SHELL;
	settings.UART_Mode_USB = (uint8_t)UART_MODE_SHELL;
}

void apply_settings(void)
{
	//Apply settings to registers
	set_reg(MAX_BRIGHTNESS,settings.max_brightness);
	set_reg(CH1_RED,settings.pwm_ch1_r);
	set_reg(CH1_GREEN,settings.pwm_ch1_g);
	set_reg(CH1_BLUE,settings.pwm_ch1_b);
	set_reg(CH2_RED,settings.pwm_ch2_r);
	set_reg(CH2_GREEN,settings.pwm_ch2_g);
	set_reg(CH2_BLUE,settings.pwm_ch2_b);
	set_reg(CH3_RED,settings.pwm_ch3_r);
	set_reg(CH3_GREEN,settings.pwm_ch3_g);
	set_reg(CH3_BLUE,settings.pwm_ch3_b);
	set_reg(CH3_WHITE,settings.pwm_ch3_w);

	//Deal with LED Strip Registers
	if (DMX_MODE2 == get_mode())
	{
		set_reg(FX_SELECT,settings.fx_select);

		set_reg(STRIP1_PATTERN,settings.strip1_pattern);
		set_reg(STRIP1_SPEED,settings.strip1_speed);
		set_reg(STRIP1_SIZE,settings.strip1_size);
		set_reg(STRIP1_COMPLEXITY,settings.strip1_complexity);
		set_reg(STRIP1_V1,settings.strip1_v1);
		set_reg(STRIP1_V2,settings.strip1_v2);
		set_reg(STRIP1_V3,settings.strip1_v3);

		set_reg(STRIP2_PATTERN,settings.strip2_pattern);
		set_reg(STRIP2_SPEED,settings.strip2_speed);
		set_reg(STRIP2_SIZE,settings.strip2_size);
		set_reg(STRIP2_COMPLEXITY,settings.strip2_complexity);
		set_reg(STRIP2_V1,settings.strip2_v1);
		set_reg(STRIP2_V2,settings.strip2_v2);
		set_reg(STRIP2_V3,settings.strip2_v3);
	}
}

bool load_settings(void)
{
	if (!EE_Reads(0,sizeof(settings_s),(uint32_t*)&settings))
	{
		print("EEPROM Read Failed");
		return false;
	}

	if ((settings.configID[0] != 'D') || (settings.configID[1] != 'M') || (settings.configID[2] != 'X') || (settings.configID[3] != 'C'))
	{
		print("No Config ID\n");
		//Create defaults
		return false;
	}
	else
	{
		//Check FW version
		if (settings.configFWversion != makeVersion())
		{
			print("Wrong Firmware Version\n");
			return false;
		}
	}
	return true;
}

void save_settings(void)
{
	if (!EE_Writes(0,sizeof(settings_s),(uint32_t*)&settings))
		print("EEPROM Write Failed");
}

void print_settings(void)
{
	print("");
	print("Defaults");
	print("-------");
	print("MAX_BRIGHTN: %d",settings.max_brightness);
	print("CH1_RED: %d",settings.pwm_ch1_r);
	print("CH1_GREEN: %d",settings.pwm_ch1_g);
	print("CH1_BLUE: %d",settings.pwm_ch1_b);
	print("CH2_RED: %d",settings.pwm_ch2_r);
	print("CH2_GREEN: %d",settings.pwm_ch2_g);
	print("CH2_BLUE: %d",settings.pwm_ch2_b);
	print("CH3_RED: %d",settings.pwm_ch3_r);
	print("CH3_GREEN: %d",settings.pwm_ch3_g);
	print("CH3_BLUE: %d",settings.pwm_ch3_b);
	print("CH3_WHITE: %d",settings.pwm_ch3_w);
	print("FX_SELECT: %d",settings.fx_select);

	print("STRIP1_PATTERN: %d",settings.strip1_pattern);
	print("STRIP1_SPEED: %d",settings.strip1_speed);
	print("STRIP1_SIZE: %d",settings.strip1_size);
	print("STRIP1_COMPLEX: %d",settings.strip1_complexity);
	print("STRIP1_V1: %d",settings.strip1_v1);
	print("STRIP1_V2: %d",settings.strip1_v2);
	print("STRIP1_V3: %d",settings.strip1_v3);

	print("STRIP2_PATTERN: %d",settings.strip2_pattern);
	print("STRIP2_SPEED: %d",settings.strip2_speed);
	print("STRIP2_SIZE: %d",settings.strip2_size);
	print("STRIP2_COMPLEX: %d",settings.strip2_complexity);
	print("STRIP2_V1: %d",settings.strip2_v1);
	print("STRIP2_V2: %d",settings.strip2_v2);
	print("STRIP2_V3: %d",settings.strip2_v3);
	print("");
	print("Settings");
	print("-------");
	//FX Multiplier
	print("FX Multiplier: %d",settings.fx_multiplier);
	print("Target FPS: %d",settings.frame_ms_target);
	//Strips
	print("Strip 1 Length: %d",settings.strip1_length);
	print("Strip 2 Length: %d",settings.strip2_length);
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

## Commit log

2020-02-04 Inital Commit
    [DMX_CTRL-B.Cu.gbr, DMX_CTRL-B.Mask.gbr, DMX_CTRL-B.SilkS.gbr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]
2020-03-01 UART and PWM working
    [DMX_CTRL.sch, DMX_CTRL.xlsx]
2020-03-01 Schematic PDF added
2020-03-04 Initial working version with PWM Control
2020-03-28 Documentation Update
    [DMX_CTRL.csv]
2020-04-09 FX Mananger Framework added
    [DMX_CTRL.xlsx]
2020-04-10 Fix Trigger, Add Plugin infrastructure
    [fx_api.c, fx_pwm_pulsing_light.c, fx_pwm_running_light.c]
2020-04-13 Support for WS2812 (WIP)
    Compiles, runs, doesn't crash... but does it work? More on this tomorrow....
    [WS2812B.c, main.c, shell_cmd.c]
2020-04-21 Add Serial DMX Protocol
    All WIP...
    [DMX_CTRL.xlsx]
2020-04-25 Bugfixes
    Fixed a few bugs, USB is working but lost WS2812B control somewhere....
    [WS2812B.c, main.c]
2020-04-29 New PCB 2.0
    [DMX_CTRL-B.Cu.gbr, DMX_CTRL-B.Mask.gbr, DMX_CTRL-B.SilkS.gbr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]
2020-04-29 Add missing files
    [DMX_CTRL.kicad_pcb]
2020-04-29 Add cylon example , update docu
    [DMX_CTRL.xlsx]
2020-06-08 Add Gamma Correction
    Add Gamma Correction via FLASH LUT (Untested...)
    [eeprom.c, gammactrl.c, light_update.c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]
2020-06-11 add platformIO support
    [DMX_CTRL.cfg, DMX_CTRL.xls]
2020-06-11 fix gamma init issue
    [gammactrl.c, main.c]
2020-06-11 test commit
    [DMX_CTRL.cfg, DMX_CTRL.xls]
2020-06-17 docu update
    [USB_TEST.cfg]
2020-06-22 Settings Version.Framerate
2020-07-09 minor updates
    [DMX_CTRL.cfg]
2020-07-11 fix PWM assignment
    [DMX_CTRL.cfg]
2020-11-25 Enclosure Design files for FreeCad
    [CTRL_BOX.stl, DMX_CTRL_BOX.FCStd, DMX_CTRL_BOX_LID.FCStd]
2021-06-02 fixed target fps command
    [settings.c, shell.c, shell_cmd.c]
2021-10-08 add timer tests, add incandescent

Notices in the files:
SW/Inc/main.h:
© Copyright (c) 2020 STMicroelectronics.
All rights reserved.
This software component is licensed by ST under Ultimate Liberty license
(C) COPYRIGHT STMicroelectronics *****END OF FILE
